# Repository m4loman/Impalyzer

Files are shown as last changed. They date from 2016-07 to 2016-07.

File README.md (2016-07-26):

# Impalyzer
Impedance (spectrum) analyzer for microelectrodes based on AD5933

This is a simple impedance spectrum analyzer. The design (especially the oscillator and the analog frontend) is specifically tuned to the analysis of microelectrodes used in electrophysiology. Even though the AD5933 comes with its own signal generator on board, it needs to be clock divided to perform excitation frequencies of around 1000Hz properly.

I need to add a bypass circuit in the next revision for electroplating but hey.. this is a good start

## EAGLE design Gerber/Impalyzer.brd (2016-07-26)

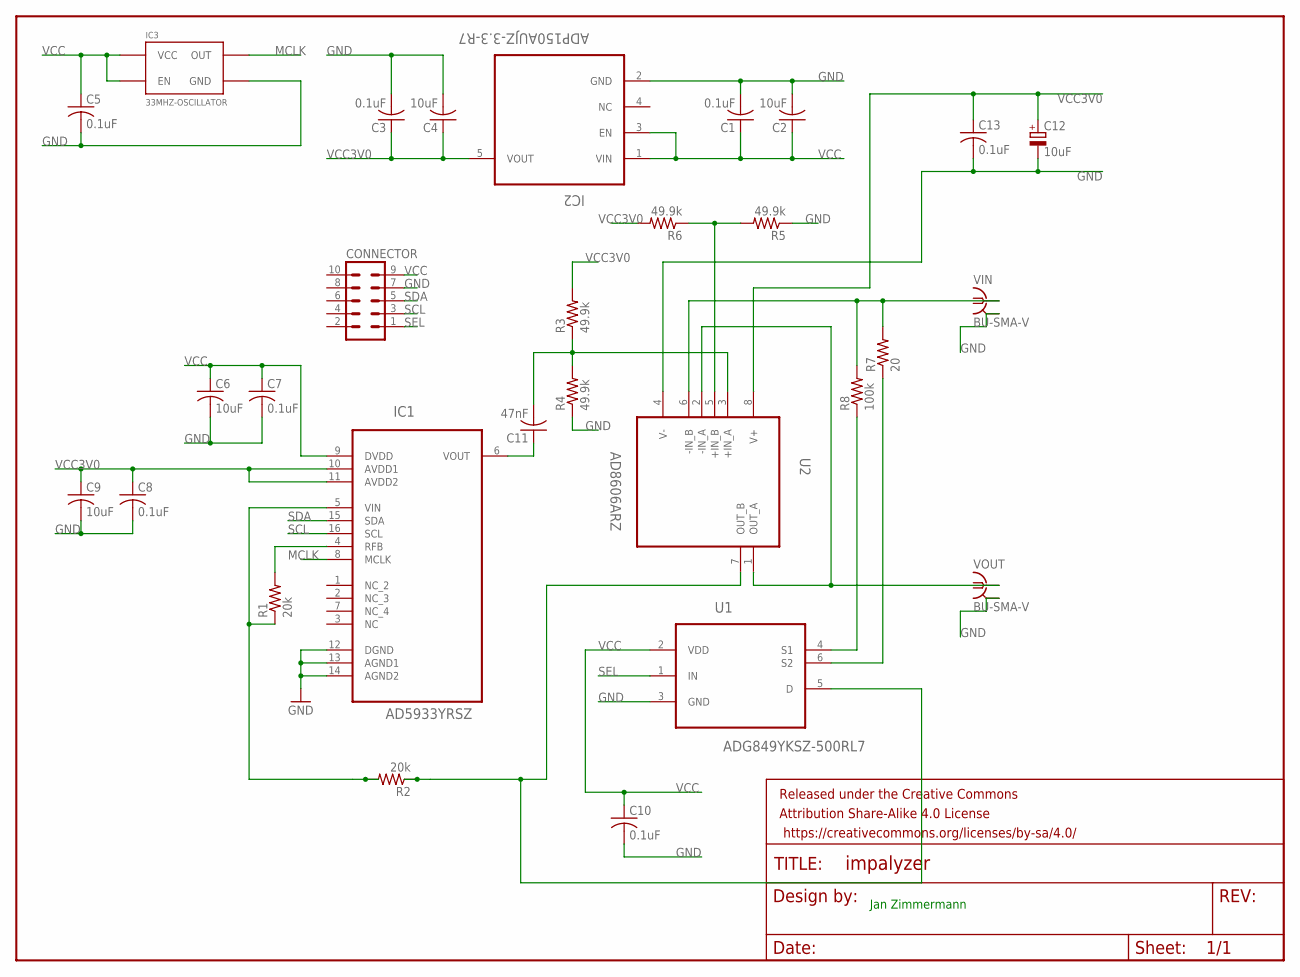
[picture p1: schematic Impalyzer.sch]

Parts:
C1, C3, C5, C7, C8, C10, C13: 0.1uF; C0402
C2, C4, C6, C9: 10uF; C0402
C11: 47nF; C0402
C12: 10uF; A/3216-18W
CONNECTOR: MA05-2
FRAME1: FRAME-LETTERNO_PACKAGE; DUMMY
IC1: AD5933YRSZ; SOP65P640X120-16N
IC2: ADP150AUJZ-3.3-R7; SOT95P280X100-5N
IC3: 33MHZ-OSCILLATOR; CRYSTAL-OSC-SMD-5X3.2
R1, R2: 20k; 0603-RES
R3, R4, R5, R6: 49.9k; 0603-RES
R7: 20; R2010
R8: 100k; 0603-RES
U1: ADG849YKSZ-500RL7; SOT65P210X110-6N
U2: AD8606ARZ; SOIC127P600X175-8N
VIN: BU-SMA-V
VOUT: BU-SMA-V

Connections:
GND: C1.2, C2.2, C3.2, C4.2, C5.2, C6.2, C7.2, C8.2, C9.2, C10.2, C12.-, C13.2, CONNECTOR.7, IC1.12 (DGND), IC1.13 (AGND1), IC1.14 (AGND2), IC2.2 (GND), IC3.2 (GND), R4.1, R5.1, U1.3 (GND), U2.4 (V-), VIN.2, VIN.3 (2), VIN.4 (2), VIN.5 (2), VOUT.2, VOUT.3 (2), VOUT.4 (2), VOUT.5 (2)
MCLK: IC1.8 (MCLK), IC3.3 (OUT)
unnamed: R2.1, U1.5 (D), U2.7 (OUT_B)
unnamed: C11.1, IC1.6 (VOUT)
unnamed: IC1.4 (RFB), R1.2
unnamed: IC1.5 (VIN), R1.1, R2.2
unnamed: U2.1 (OUT_A), U2.2 (-IN_A), VOUT.1
unnamed: R7.2, R8.2, U2.6 (-IN_B), VIN.1
unnamed: C11.2, R3.1, R4.2, U2.3 (+IN_A)
unnamed: R5.2, R6.1, U2.5 (+IN_B)
unnamed: R8.1, U1.4 (S1)
unnamed: R7.1, U1.6 (S2)
SCL: CONNECTOR.3, IC1.16 (SCL)
SDA: CONNECTOR.5, IC1.15 (SDA)
SEL: CONNECTOR.1, U1.1 (IN)
VCC: C1.1, C2.1, C5.1, C6.1, C7.1, C10.1, CONNECTOR.9, IC1.9 (DVDD), IC2.1 (VIN), IC2.3 (EN), IC3.1 (EN), IC3.4 (VCC), U1.2 (VDD)
VCC3V0: C3.1, C4.1, C8.1, C9.1, C12.+, C13.1, IC1.10 (AVDD1), IC1.11 (AVDD2), IC2.5 (VOUT), R3.2, R6.2, U2.8 (V+)

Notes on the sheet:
Jan Zimmermann

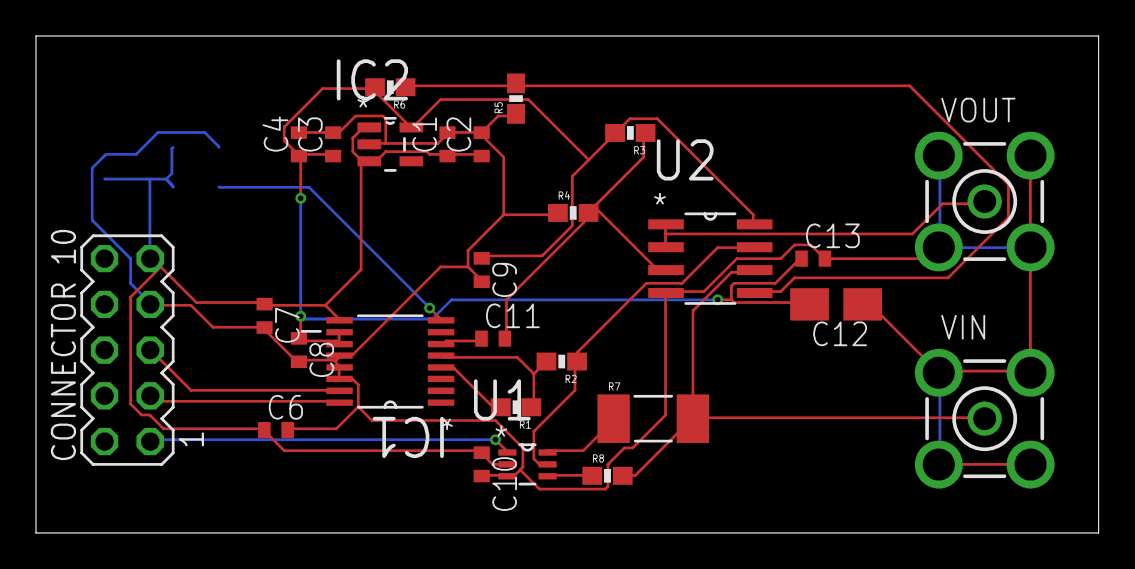
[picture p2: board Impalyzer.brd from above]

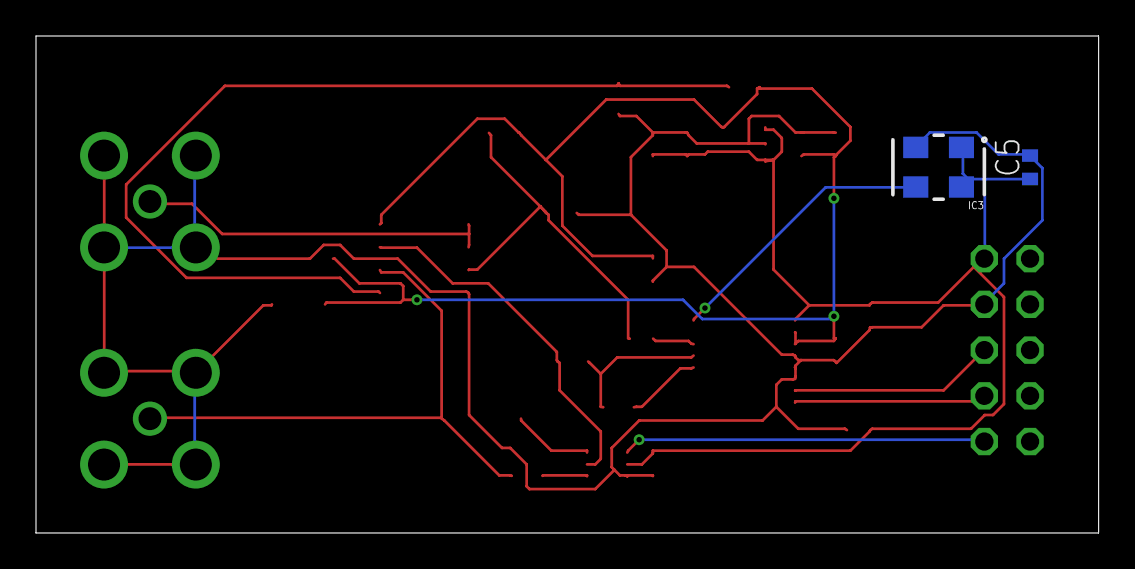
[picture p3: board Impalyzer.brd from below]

Board: 2 copper layers, 59.0 x 27.6 mm, 30 parts (2 on the bottom side), 17 nets.

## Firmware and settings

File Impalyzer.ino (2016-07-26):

/*********************

IMPALYZER
Impedance analyzer based on AD5933

Jan Zimmermann 2016
maloman@gmail.com

Part of the code is based on:
Adafruit RGB_LCD_Library
AD5933 Library from Analog Devices as well as code from Z_Logger

**********************/

// includes
#include <Wire.h>
#include <Adafruit_RGBLCDShield.h>
#include <utility/Adafruit_MCP23017.h>
#include "AD5933.h"

Adafruit_RGBLCDShield lcd = Adafruit_RGBLCDShield();

// Some definitions for the display and AD5933
#define WHITE 0x7
#define TWI_FREQ 400000L
#define cycles_base 200
#define cycles_multiplier 4
#define start_frequency 1000
#define cal_samples 30

const int numofIncrement = 1;
const double calResistance = 100000;
double gainFactor, pShift;

void setup() {
  // Debugging output
  Wire.begin();
  Serial.begin(9600);

  // set up the LCD's number of columns and rows:
  lcd.begin(16, 2);

  lcd.print("IMPALYZER 0.1");
  lcd.setBacklight(WHITE);
  // set up AD5933
  AD5933.setExtClock(true);
  AD5933.resetAD5933();
  AD5933.setStartFreq(start_frequency);
  AD5933.setSettlingCycles(cycles_base, cycles_multiplier);
  AD5933.setStepSizeInHex(1);
  AD5933.setNumofIncrement(2);
  AD5933.setPGA(GAIN_1);
  AD5933.setRange(RANGE_1);

}
uint8_t sel_mode = 0;
uint8_t i=0;
void loop() {
  lcd.setCursor(0, 1);
  double temp = AD5933.getTemperature();
  AD5933.tempUpdate();

  uint8_t buttons = lcd.readButtons();

  if (buttons) {
    lcd.clear();
    lcd.setCursor(0,0);
    
      if (buttons & BUTTON_UP) {
        lcd.print("AD5933 TEMP (C) ");
        lcd.setCursor(0,1);
        lcd.print(temp);
        lcd.print((char)223);
        sel_mode = 0;
      }
      
      if (buttons & BUTTON_DOWN) {
        AD5933.setCtrMode(REPEAT_FREQ);
        lcd.print("Impedance");
        lcd.setCursor(0,1);
        double cReal, cImag;
        double Z_Val, phase;
        AD5933.getComplex(gainFactor, pShift, Z_Val, phase);
        lcd.print(Z_Val/1000);
        lcd.print('k');
        lcd.print((char)244);
        lcd.print(" ");
        lcd.print(phase);
        lcd.print((char)223);
        sel_mode = 1;
      }
      
       if (buttons & BUTTON_SELECT & (sel_mode == 1)) {
        while (sel_mode == 1){
          AD5933.setCtrMode(REPEAT_FREQ);
          lcd.print("Impedance");
          lcd.setCursor(0,1);
          double cReal, cImag;
          double Z_Val, phase;
          AD5933.getComplex(gainFactor, pShift, Z_Val, phase);
          lcd.print(Z_Val/1000);
          lcd.print('k');
          lcd.print((char)244);
          lcd.print(" ");
          lcd.print(phase);
          lcd.print((char)223);
        }   
      }
    
      if (buttons & BUTTON_LEFT) {
        lcd.print("Cal with 100k");
        lcd.print((char)244);
        sel_mode = 2;
      }
      
       if (buttons & BUTTON_SELECT & (sel_mode == 2)) {
        AD5933.getGainFactor(calResistance, cal_samples, gainFactor, pShift, false);
        lcd.setCursor(0,0);
        lcd.print("Gain: ");
        lcd.print(gainFactor);
        lcd.setCursor(0,1);
        lcd.print("SpS: ");
        lcd.print(pShift);
        sel_mode = 1;       
      }
      
      if (buttons & BUTTON_RIGHT) {
        lcd.print("nothing here ");
        sel_mode = 0;
      }
}
}

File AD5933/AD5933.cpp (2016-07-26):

// Library Code Section of AD5933

// Author: Il-Taek Kwon

// Modifications: Adetunji Dahunsi
// Modifications: Jan Zimmermann

#include "AD5933.h"
//#include <WProgram.h>
#include <Arduino.h> // For the compatibility with Arduino Conventions.
//#include <WConstants.h>

AD5933_Class AD5933;

/**
 * Gets the temperature of the AD5933
 */

double AD5933_Class::getTemperature() {

	if ( tempUpdate() == false )
		return -1;

	int tTemp[2];
	long tTempVal;
	double cTemp;

	tTemp[0] = getByte(0x92);
	tTemp[1] = getByte(0x93);
	tTempVal = (tTemp[0] % (12 * 16)) * 16 * 16 + tTemp[1];
	if (bitRead(tTemp[0], 5) == 0)
	{
		// Positive Formula
		cTemp = (double)tTempVal / 32;
	}
	else
	{
		// Negative Formula
		cTemp = (tTempVal - 16384.0) / 32;
	}
#if LOGGING1
	printer->print("getTemperature - Current Temp. is ");
	printer->print(cTemp);
	printer->print("\n");
#endif

	return cTemp;
}

/*
 * Updates temperature information without writing to a variable.
 */

bool AD5933_Class::tempUpdate() {

	if (setCtrMode(TEMP_MEASURE) == false)
	{
#if LOGGING1
		printer->println("tempUpdate - Failed to set the control bit");
#endif
		return false;
	}

	while ( (getStatusReg() & 0x01) != 0x01)
	{
		; // Wait Until Get Vaild Temp. Measurement.
	}

	return true;
}

/**
 * Sets the Reset Bit (D4) in control register 0x81.
 */

bool AD5933_Class::resetAD5933() {

	int temp = (getByte(0x81) & 0x08); // Read 0x81 with retrieving D3
	return setByte(0x81, (temp | 0x10)); // Set D4 as 1 (Reset Bit)
}

/**
 * A function to enable/disable external clock.
 *
 * This function also sets the environmental variable (double opClock)
 *
 * @Param swt True uses an external clook.
 */

bool AD5933_Class::setExtClock(bool swt) {
	byte t1;
	if ( swt )
	{
		t1 = 0x08; // Use Ext. Clock
		opClock = 1843200;
	}
	else
	{
		t1 = 0x00; // Use Int. Clock
		opClock = 16776000;
	}
	return setByte(0x81, t1); // Write register 0x81.
}

/**
 * Sets the number of settling cycles before a measurement is taken.
 *
 * @Param cycles Cycles to ignore before a measurement is taken. Max is 511.
 * @Param mult Multiplier for cycles. Can be 1, 2, or 4.
 */

bool AD5933_Class::setSettlingCycles(int cycles, byte mult) {

	if (cycles > 0x1FF || !(mult == 1 || mult == 2 || mult == 4) ){
#if LOGGING1
		printer->println("setSettlingCycles - Invalid Parameter");
#endif
		return false;
	}
	int lowerHex = cycles % 256;
	int upperHex = ((cycles - (long)lowerHex) >> 8) % 2;
	byte t1; // Parsing upper and lower bits.
	/*switch(mult)
    {
      case 1:
        t1 = 0;
        break;
      case 2:
        t1 = 1;
        break;
      case 4:
        t1 = 3;
        break;
      default:
  #if LOGGING1
      printer->println("setSettlingCycles - Invalid Mult Parameter");
  #endif
      return false;
      break;
    }*/
	t1--; // Enhanced Code for setting t1.
	upperHex |= (t1 << 1);  // t1 is for D9, D10. The upperHex just accounts for D8. Thus, the value after left-shifting t1 accounts for D9, D10.
	// Thus, this above writes bits for D9, D10.
#if LOGGING2
	printer->print("setSettlingCycles - upper: ");
	printer->println(upperHex, BIN);
#endif
	bool t2, t3;
	t2 = setByte(0x8A, upperHex);
	t3 = setByte(0x8B, lowerHex);
	if ( t2 && t3 ) // Checking if successful.
		return true;  // Succeed!
	else
	{
#if LOGGING1
		printer->println("setSettingCycles - Data Write Fail");
#endif
		return false;
	}
}


/**
 * Sets the start frequency for a frequency sweep in hertz.
 *
 * @Param startFreq The start frequency
 */
bool AD5933_Class::setStartFreq(long startFreq) {

#if LOGGING3
	//double t1 = opClock / pow(2,29);
	//printer->println(t1);
#endif
	long freqHex = startFreq / (opClock / pow(2, 29)); // based on datasheet
	if (freqHex > 0xFFFFFF)
	{
#if LOGGING1
		printer->print("setStartFreq - Freqeuncy Overflow!");
#endif
		return false;
	}

	int lowerHex = freqHex % 256;
	int midHex = ((freqHex - (long)lowerHex) >> 8) % 256;
	int upperHex = freqHex >> 16;
#if LOGGING3
	printer->print("setStartFreq - freqHex: ");
	printer->print(freqHex, HEX);
	printer->print("\t");
	printer->print("lower: ");
	printer->print(lowerHex, HEX);
	printer->print("\t");
	printer->print("mid: ");
	printer->print(midHex, HEX);
	printer->print("\t");
	printer->print("upper: ");
	printer->print(upperHex, HEX);
	printer->println();
#endif
	bool t2, t3, t4;
	t2 = setByte(0x82, upperHex);
	t3 = setByte(0x83, midHex);
	t4 = setByte(0x84, lowerHex);
	if (t2 && t3 && t4)
		return true; // succeed!
	else
	{
#if LOGGING1
		printer->println("setStartFreq - Data Transmission Failed!");
#endif
		return false;
	}
}

/**
 * Sets the step size for a frequency sweep in hertz.
 *
 * NOTE: because the increment frequency should be converted into unique hexadecimal number,
 * it approximately calculates the Hex value.
 *
 * @Param increment The stepSize in hertz
 */

bool AD5933_Class::setStepSize(long increment) {

	long freqHex = increment / (opClock / pow(2, 29)); // Based on the data sheet.
	return setStepSizeInHex(freqHex); // Call setIncrementinHex(long);
}

/**
 * Sets the step size for a frequency sweep in using hexadecimal values.
 *
 * The value is calculated based on the datasheet.
 *
 * @Param freqHex The converted hexadecimal value
 */

bool AD5933_Class::setStepSizeInHex(long freqHex) {

	if (freqHex > 0xFFFFFF)
	{
#if LOGGING1
		printer->print("setIncrementHex - Freqeuncy Overflow!");
#endif
		return false;
	}

	int lowerHex = freqHex % 256;
	int midHex = ((freqHex - (long)lowerHex) >> 8) % 256;
	int upperHex = freqHex >> 16;

	bool t2, t3, t4;
	t2 = setByte(0x85, upperHex);
	t3 = setByte(0x86, midHex);
	t4 = setByte(0x87, lowerHex);
	if (t2 && t3 && t4)
	{
		incrHex = freqHex;
		return true; // Succeed!
	}
	else
	{
#if LOGGING1
		printer->println("setIncrementHex - Data Transmission Failed!");
#endif
		return false;
	}

}

/**
 * Sets the number of frequency increments in a frequency sweep. The AD5933 is rated for 1 - 100 KHZ.
 * You may go higher at the risk of larger errors.
 *
 * NOTE: This is the number of increments, not the total number of points in the sweep. An Increment of 5
 * means a total of 6 frequency points.
 *
 * @Param num Number of increments
 */

bool AD5933_Class::setNumofIncrement(byte num) {

	if (num > 0x1FF + 1)
	{
#if LOGGING1
		printer->print("setNumofIncrement - Frequency Overflow!");
#endif
		return false;
	}

	int lowerHex = num % 256;
	int upperHex = (num >> 8) % 2; // Parsing number for register input.

	bool t2, t4;
	t2 = setByte(0x88, upperHex);
	t4 = setByte(0x89, lowerHex);
	if (t2 && t4)
	{
		numIncrement = num + 1;
		return true; // Succeed!
	}
	else
	{
#if LOGGING1
		printer->println("setNumofIncrement - Data Transmission Failed!");
#endif
		return false;
	}
}
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

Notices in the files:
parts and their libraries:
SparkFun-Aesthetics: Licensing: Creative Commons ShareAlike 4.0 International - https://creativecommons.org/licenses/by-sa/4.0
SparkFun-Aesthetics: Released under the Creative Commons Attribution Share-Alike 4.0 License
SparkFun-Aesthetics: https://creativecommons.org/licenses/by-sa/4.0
